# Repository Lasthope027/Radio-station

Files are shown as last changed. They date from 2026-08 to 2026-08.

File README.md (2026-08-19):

# 100 MHz FM Transmitter

## Overview

This repository contains the design and simulation files for a **100 MHz FM transmitter**, including the transmitter circuit, PCB design, manufacturing files, and a dedicated 100 MHz antenna design.

The project covers the workflow from **circuit simulation and PCB design to antenna modeling**.

For detailed technical specifications, design methodology, calculations, and simulation results, refer to the **[FM Radio Transmitter.pdf](FM%20Radio%20Transmitter.pdf)** included in this repository.

---

## Repository Structure

The repository is organized into the following sections:

- **Antenna/** — Contains the 100 MHz antenna model.
- **Transmitter/** — Contains the LTspice transmitter circuit and KiCad PCB design files.
- **FM Radio Transmitter.pdf** — Contains the detailed technical documentation and simulation results.
- **README.md** — Provides an overview and guide to the repository.

---

## Antenna

The `Antenna/` folder contains the antenna model designed specifically for operation at **100 MHz**.

### File

`FM Antenna.maa`

The `.maa` file can be opened using **MMANA-GAL** to inspect and simulate the antenna design.

**Software:** MMANA-GAL

---

## Transmitter

The `Transmitter/` folder contains the transmitter circuit and PCB design files.

### LTspice Circuit

The `Circuit .asc` file contains the transmitter schematic and can be opened using **LTspice** to inspect the circuit and reproduce the simulation.

**Software:** LTspice

### KiCad Files

The `KiCad/` folder contains the schematic, PCB layout, and manufacturing files.

- `RF Transmitter.kicad_sch` — KiCad schematic
- `RF Transmitter.kicad_pcb` — PCB layout
- `Gerber.zip` — Gerber files prepared for PCB fabrication

**Software:** KiCad

---

## Documentation

The `FM Radio Transmitter.pdf` contains the detailed technical documentation of the project, including the design, calculations, circuit analysis, simulation results, and antenna analysis.

For complete technical details, refer to the **[FM Radio Transmitter.pdf](FM%20Radio%20Transmitter.pdf)**.

---

## Software Used

| Software | Purpose |
|---|---|
| **LTspice** | Transmitter circuit design and simulation |
| **KiCad** | Schematic and PCB design |
| **MMANA-GAL** | 100 MHz antenna modeling and simulation |

---

## How to Explore the Repository

- To inspect the **transmitter circuit**, open the `.asc` file using LTspice.
- To inspect the **PCB schematic**, open the `.kicad_sch` file using KiCad.
- To inspect the **PCB layout**, open the `.kicad_pcb` file using KiCad.
- To fabricate the PCB, use the **Gerber.zip** manufacturing files.
- To inspect the **100 MHz antenna**, open the `.maa` file using MMANA-GAL.
- For detailed technical specifications, calculations, and simulation results, refer to the **FM Radio Transmitter PDF**.

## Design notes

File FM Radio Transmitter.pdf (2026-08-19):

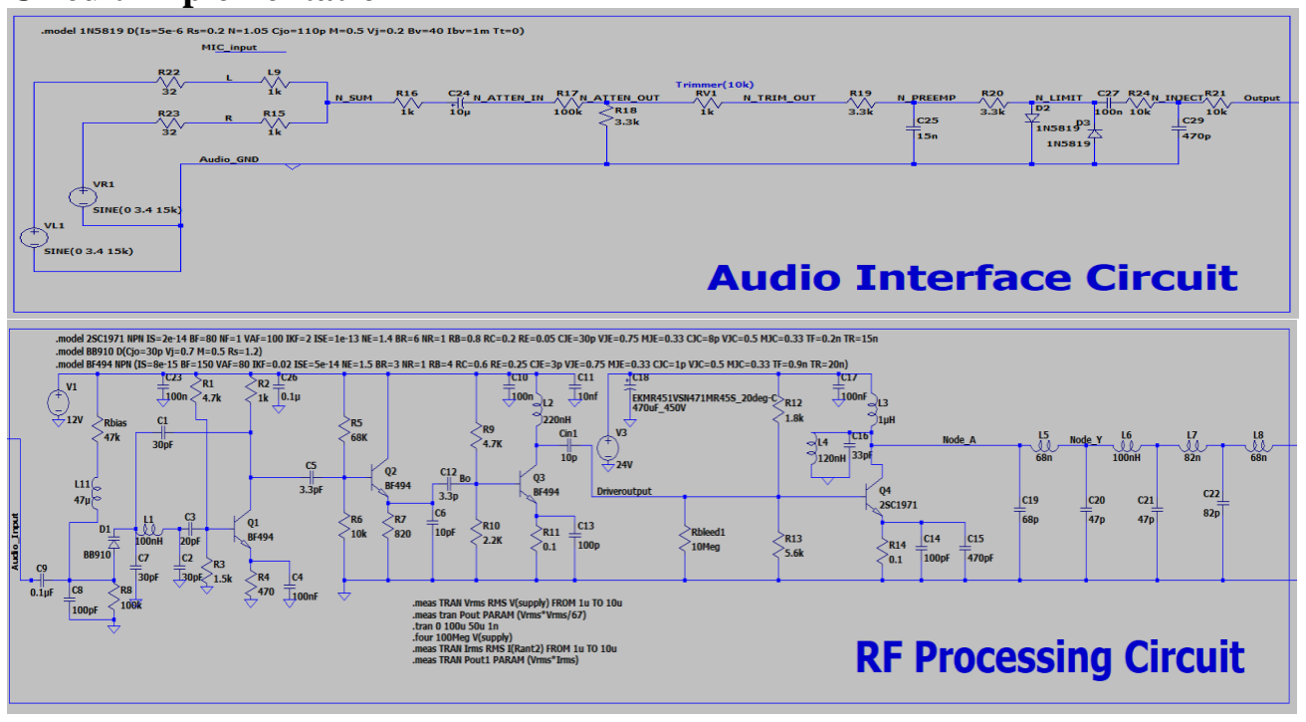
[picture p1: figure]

1

Audio Input Sources: Receives audio signals from microphones, mixers, or other compatible audio devices for transmission.

Summing Network: Combines multiple audio signals into a single output while maintaining balanced signal levels.

AC Coupling / High-Pass Filter: Eliminates DC components and attenuates unwanted low-frequency noise from the input signal.

Audio Level Control: Regulates the audio amplitude to achieve the required modulation level without over-modulation.

Trim / Gain Adjust: Provides fine control over the input gain to ensure consistent audio performance.

Pre-Emphasis Filter: Enhances higher-frequency audio components to improve the signal-to-noise ratio during FM transmission.

Limiter (Diode Clipper): Restricts excessive signal peaks, preventing distortion and maintaining stable modulation.

Injection / Coupling Network: Couples the processed audio signal to the RF oscillator while preserving oscillator stability.

FM Oscillator (Varactor + VCO): Generates a stable carrier at approximately 100 MHz, with its frequency varying according to the input audio signal.

Buffer Amplifier: Isolates the oscillator from subsequent stages, preventing frequency shifts caused by load variations.

Driver Amplifier: Amplifies the RF signal to a level sufficient for driving the final power amplifier.

RF Power Amplifier: Increases the RF signal power to approximately 2 W for effective transmission.

Impedance Matching Network: Matches the output impedance of the amplifier with the antenna to maximize power transfer and minimize reflected power.

RF Low-Pass Filter: Suppresses harmonic frequencies and unwanted spectral components before the RF signal reaches the antenna.

RF Output (Antenna): Radiates the amplified RF signal into free space, enabling wireless FM broadcasting.

# FM Radio Transmitter

# System Workflow

# Circuit Implementation

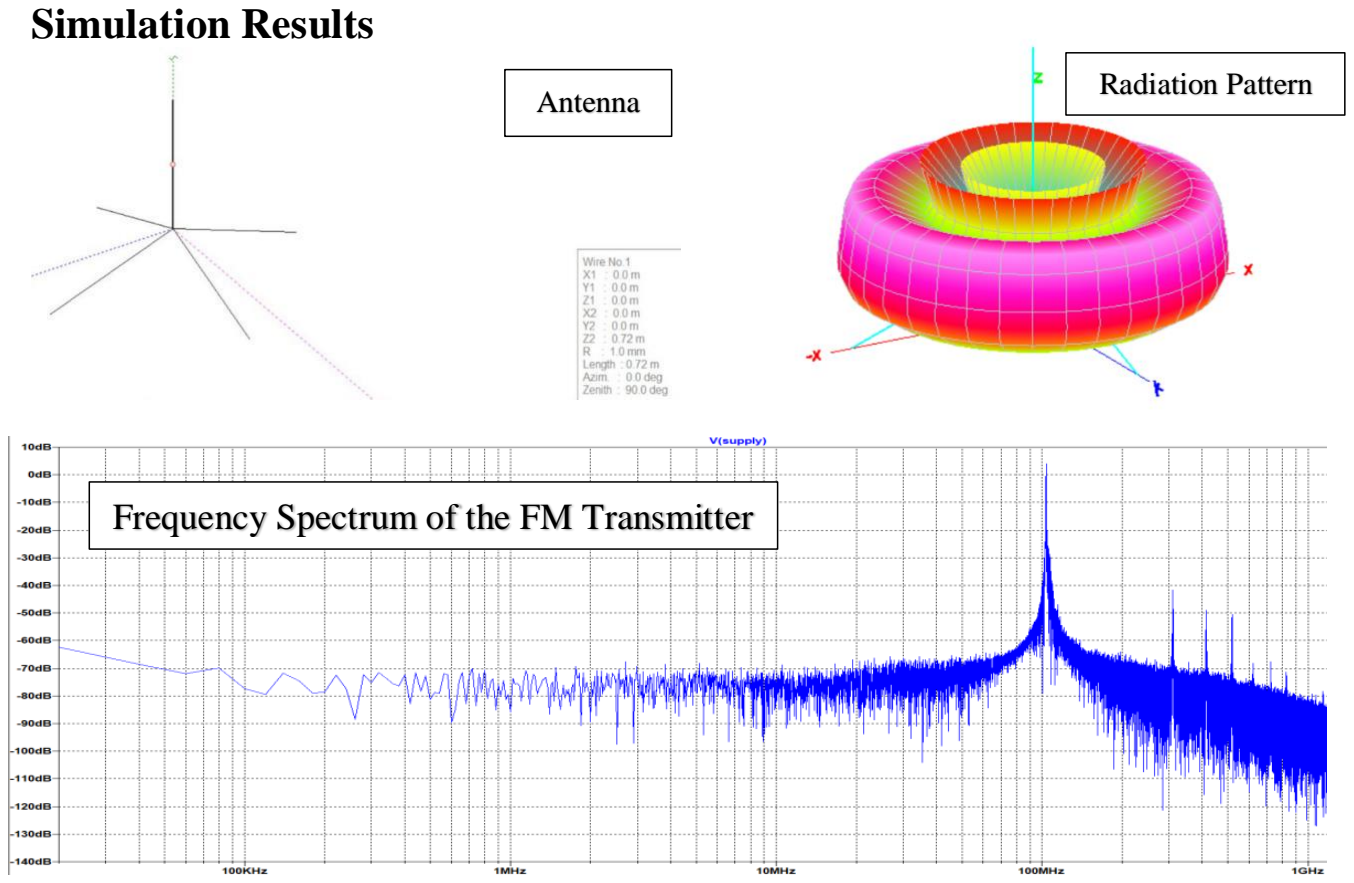
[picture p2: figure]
Simulation Results; Antenna; Radiation Pattern

2

## The complete transmitter and antenna system were verified through circuit and electromagnetic simulations. LTspice analysis confirmed stable operation of the RF transmitter with a carrier frequency of approximately 100 MHz, an estimated RF

## output power of 2.4 W, and a Total Harmonic Distortion (THD) of approximately

3.18%, | indicating | acceptable | spectral | performance. | Antenna | simulations

## demonstrated effective impedance matching with an SWR of approximately 1.34, a feed-point impedance of 66.85 − j0.18 Ω. The obtained radiation pattern and matching characteristics indicate that the antenna is well suited for efficient operation

in the FM broadcast band.

## Frequency Spectrum of the FM Transmitter

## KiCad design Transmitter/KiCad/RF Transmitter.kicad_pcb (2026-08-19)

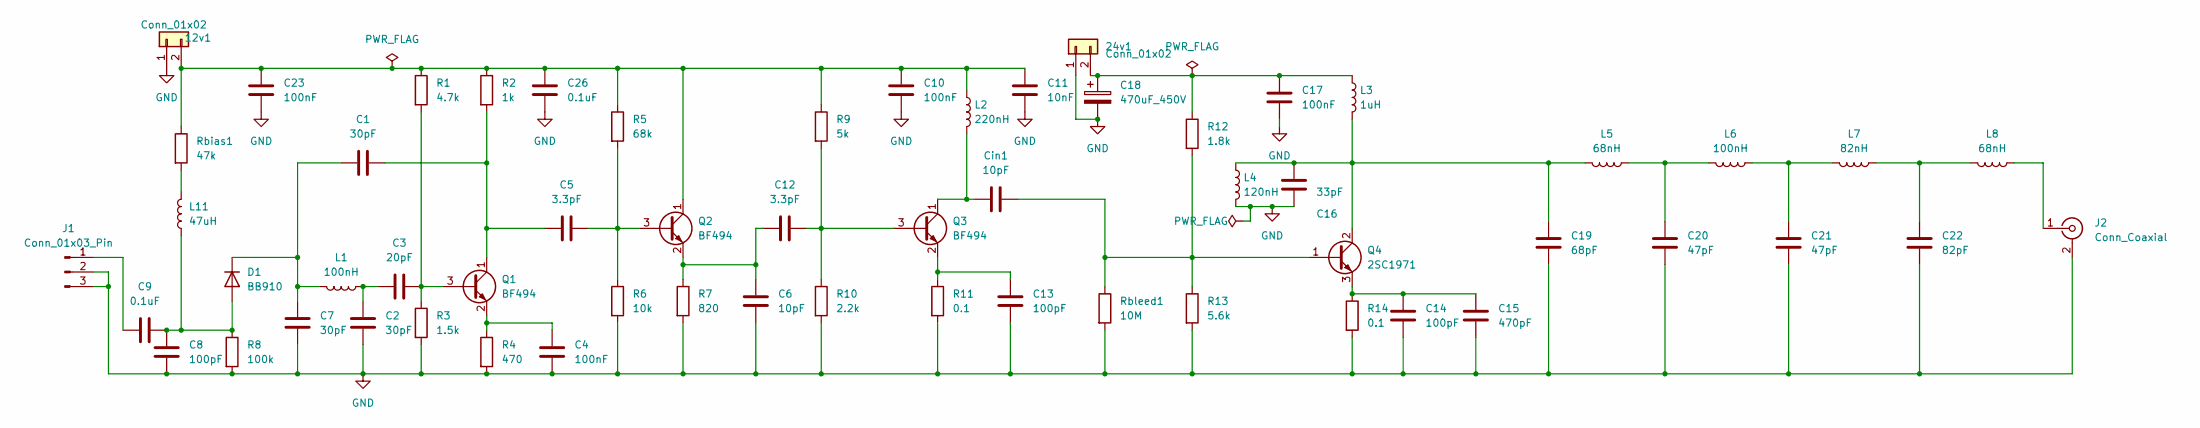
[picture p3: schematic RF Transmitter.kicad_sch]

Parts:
12v1, 24v1: Conn_01x02
C1, C2, C7: 30pF; C_0603_1608Metric
C3: 20pF; C_0603_1608Metric
C4, C10, C17, C23: 100nF; C_0805_2012Metric
C5, C12: 3.3pF; C_0603_1608Metric
C6: 10pF; C_0603_1608Metric
C8, C13, C14: 100pF; C_0603_1608Metric
C9, C26: 0.1uF; C_0805_2012Metric
C11: 10nF; C_0805_2012Metric
C15: 470pF; C_0603_1608Metric
C16: 33pF; C_0603_1608Metric
C18: 470uF_450V; CP_Radial_D10.0mm_P5.00mm
C19: 68pF; C_0603_1608Metric
C20, C21: 47pF; C_0603_1608Metric
C22: 82pF; C_0603_1608Metric
Cin1: 10pF; C_0603_1608Metric
D1: BB910; TO-92_Inline
J1: Conn_01x03_Pin; JST_PH_B3B-PH-K_1x03_P2.00mm_Vertical
J2: Conn_Coaxial; SMA_Amphenol_901-144_Vertical
L1, L6: 100nH; L_0603_1608Metric
L2: 220nH; L_0603_1608Metric
L3: 1uH; L_0805_2012Metric
L4: 120nH; L_0603_1608Metric
L5, L8: 68nH; L_0603_1608Metric
L7: 82nH; L_0603_1608Metric
L11: 47uH; L_0805_2012Metric
Q1, Q2, Q3: BF494; TO-92_Inline
Q4: 2SC1971; TO-220-3_Vertical
R1: 4.7k; R_Axial_DIN0207_L6.3mm_D2.5mm_P7.62mm_Horizontal
R2: 1k; R_Axial_DIN0207_L6.3mm_D2.5mm_P7.62mm_Horizontal
R3: 1.5k; R_Axial_DIN0207_L6.3mm_D2.5mm_P7.62mm_Horizontal
R4: 470; R_Axial_DIN0207_L6.3mm_D2.5mm_P7.62mm_Horizontal
R5: 68k; R_Axial_DIN0207_L6.3mm_D2.5mm_P7.62mm_Horizontal
R6: 10k; R_Axial_DIN0207_L6.3mm_D2.5mm_P7.62mm_Horizontal
R7: 820; R_Axial_DIN0207_L6.3mm_D2.5mm_P7.62mm_Horizontal
R8: 100k; R_Axial_DIN0207_L6.3mm_D2.5mm_P7.62mm_Horizontal
R9: 5k; R_Axial_DIN0207_L6.3mm_D2.5mm_P7.62mm_Horizontal
R10: 2.2k; R_Axial_DIN0207_L6.3mm_D2.5mm_P7.62mm_Horizontal
R11, R14: 0.1; R_Axial_DIN0411_L9.9mm_D3.6mm_P12.70mm_Horizontal
R12: 1.8k; R_Axial_DIN0207_L6.3mm_D2.5mm_P7.62mm_Horizontal
R13: 5.6k; R_Axial_DIN0207_L6.3mm_D2.5mm_P7.62mm_Horizontal
Rbias1: 47k; R_Axial_DIN0207_L6.3mm_D2.5mm_P7.62mm_Horizontal
Rbleed1: 10M; R_Axial_DIN0207_L6.3mm_D2.5mm_P7.62mm_Horizontal

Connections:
GND: 12v1.1, 24v1.1, C2.2, C4.2, C6.2, C7.2, C8.2, C10.2, C11.2, C13.2, C14.2, C15.2, C16.2, C17.2, C18.2, C19.2, C20.2, C21.2, C22.2, C23.2, C26.2, J1.2, J1.3, J2.2 (Ext), L4.2, R3.2, R4.2, R6.2, R7.2, R8.2, R10.2, R11.2, R13.2, R14.2, Rbleed1.2
unnamed: 12v1.2, C10.1, C11.1, C23.1, C26.1, L2.1, Q2.1 (C), R1.1, R2.1, R5.1, R9.1, Rbias1.1
unnamed: 24v1.2, C17.1, C18.1, L3.1, R12.1
unnamed: C2.1, C3.1, L1.1
unnamed: C20.1, L5.1, L6.2
unnamed: C21.1, L6.1, L7.2
unnamed: C22.1, L7.1, L8.2
unnamed: C8.1, C9.2, D1.2 (A), L11.1, R8.1
unnamed: C1.1, C7.1, D1.1 (K), L1.2
unnamed: C9.1, J1.1
unnamed: J2.1 (In), L8.1
unnamed: L11.2, Rbias1.2
unnamed: C3.2, Q1.3 (B), R1.2, R3.1
unnamed: C1.2, C5.1, Q1.1 (C), R2.2
unnamed: C4.1, Q1.2 (E), R4.1
unnamed: C5.2, Q2.3 (B), R5.2, R6.1
unnamed: C6.1, C12.1, Q2.2 (E), R7.1
unnamed: C12.2, Q3.3 (B), R9.2, R10.1
unnamed: Cin1.1, L2.2, Q3.1 (C)
unnamed: C13.1, Q3.2 (E), R11.1
unnamed: Cin1.2, Q4.1 (B), R12.2, R13.1, Rbleed1.1
unnamed: C16.1, C19.1, L3.2, L4.1, L5.2, Q4.2 (C)
unnamed: C14.1, C15.1, Q4.3 (E), R14.1

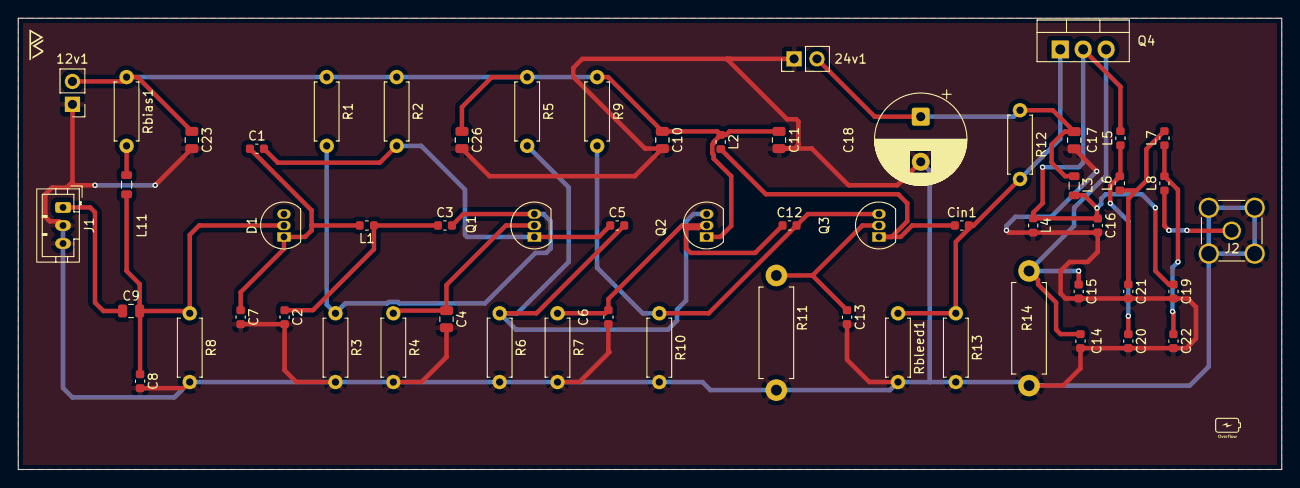
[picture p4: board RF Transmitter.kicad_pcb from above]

Board: 2 copper layers, 140.0 x 50.0 mm, 59 parts (0 on the bottom side), 23 nets.

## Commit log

2026-08-19 Rename Circuit .asc to LTspice Circuit .asc
2026-08-19 Add .getkeep file to KiCad directory
2026-08-19 Rename LTspice Circuit .asc to Circuit .asc
